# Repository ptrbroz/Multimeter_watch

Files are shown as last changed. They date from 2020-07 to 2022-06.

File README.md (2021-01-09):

# An open-source multimeter watch

Contained herein is the multimeter watch project, developed by Petr Brož and David Šibrava. It is a multimeter small enough to wear on your wrist!  It utilizes the LGT8F328P-QFP32L CPU. 

The developement is ongoing, thus the project's kicad folders are split into different versions for different versions of the hardware:

# V1 prototype

The first version consists of two pcbs, mated via pin headers. The upper pcb holds the I2C display and buttons, as well as the buzzer circuit.  

The bottom pcb holds the CPU, three 3.5mm jack connectors (for custom multimeter probes) and other circuitry.

Sandwiched between the two pcbs is a Li-Po battery, rechargeable via the aforementioned pin headers.

It's features include:

- Timekeeping via I2C RTC
- Voltage, current measuring
- RLC tester functionality
- Programmable current source/sink
- Programmable I2C communication
- Buzzer

For photos of hardware, please scroll to [photos](#Photos).

# V2

The V2 hardware improves upon the V1 in several aspects:

- It changes the signal connection between the top and bottom PCBs from using pin headers to a flex cable. The boards are now held together by screws, allowing for much smaller vertical size. (~halved compared to V1 (todo:add measurements))
- 3.5 jack connectors replaced by S3B-PH-K-S connectors (jacks had poor structural integrity and would come loose with repeated insertions of probes).
- Buzzer circuitry moved to bottom PCB (to allow another slight decrease in vertical dimension).
- Various layout optimizations leading to smaller PCB footprint (42x46mm in V2 as opposed to 46x55mm in V1)

Perhaps most significant is the following improvement:

- Add alternative top PCB which utilizes capacitance-sensing buttons on the PCB itself instead of physical buttons. As the capacitance sensing is driven by an I2C device (an AT42QT1070-S located on the bottom side of the top PCB), 6 pins of the CPU are freed from being used as button inputs.

Thus, when the V2 version is used with the capacitance touch top PCB, up to 6 GPIO pins become available to the user.

# Photos

V1:
(10 CZK coin for scale (diameter = 24.5mm))
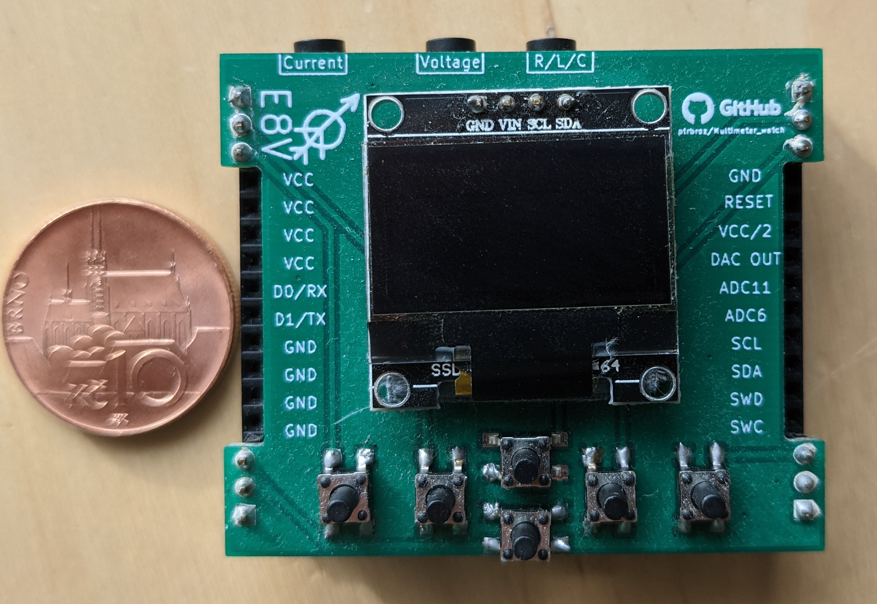
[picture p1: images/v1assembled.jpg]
v1assembled

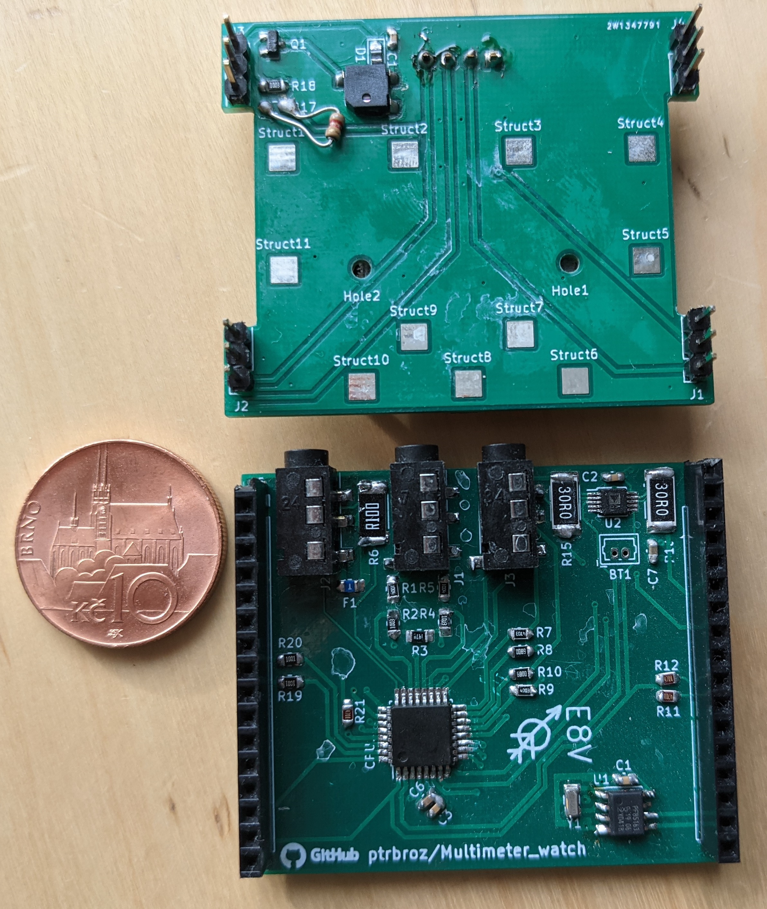
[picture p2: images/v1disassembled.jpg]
v1disassembled

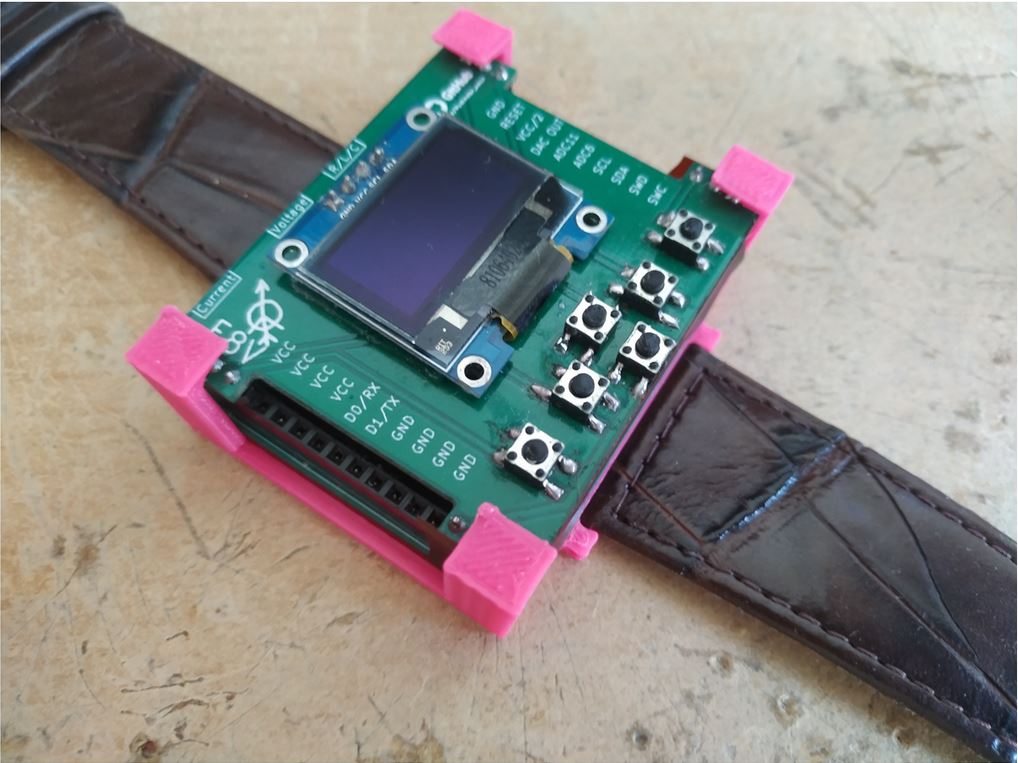
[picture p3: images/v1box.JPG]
v1box


V2:
(to be photographed)

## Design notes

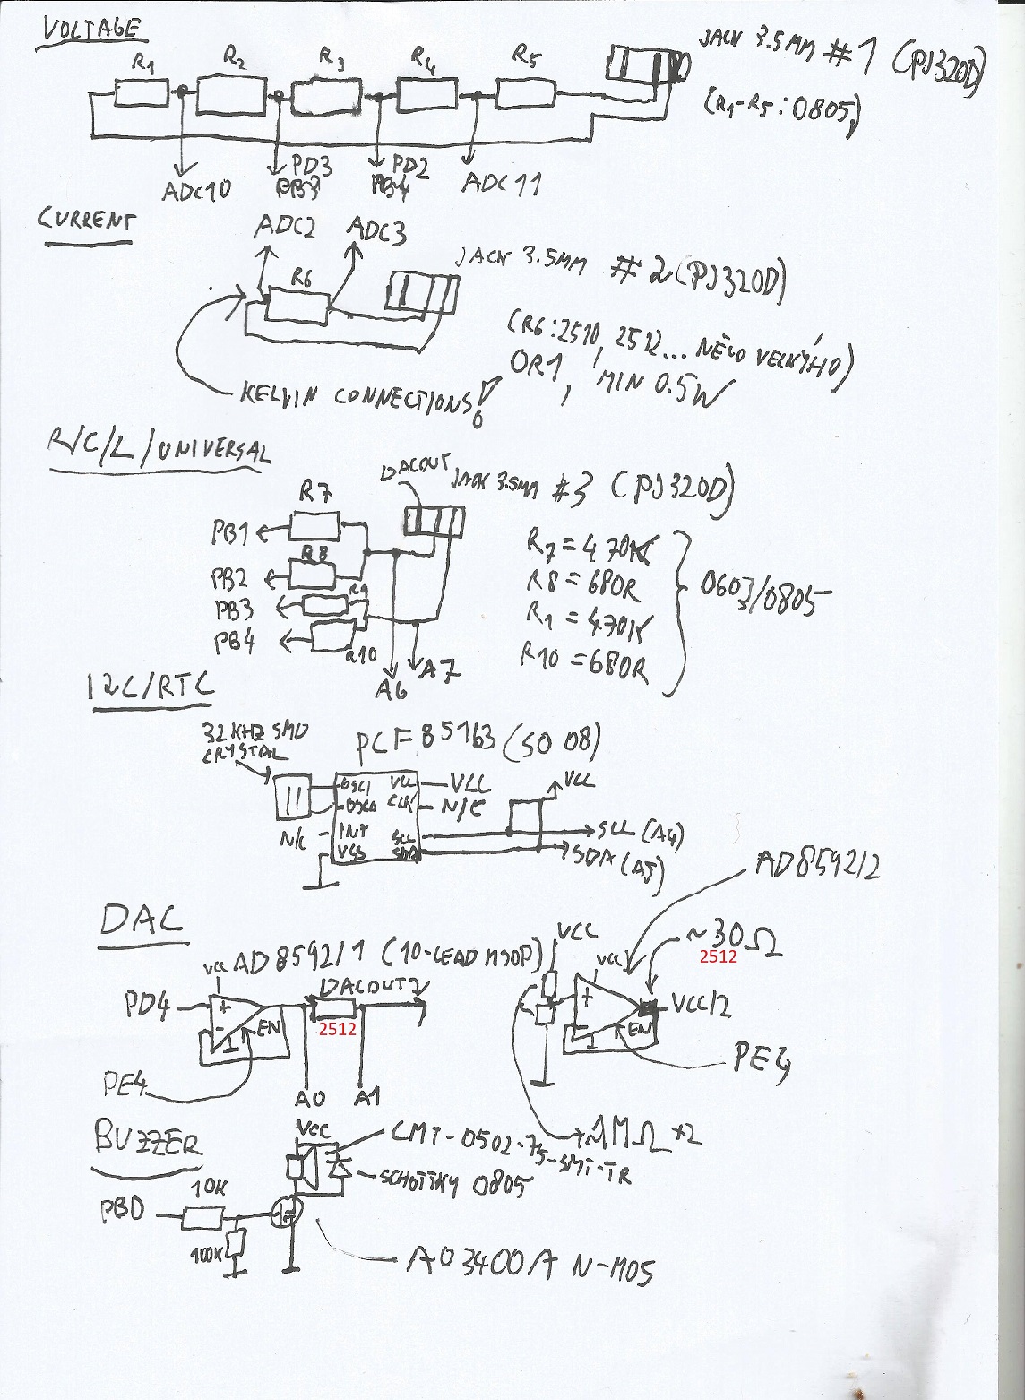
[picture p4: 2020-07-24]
SchemaSketch/page1.jpg

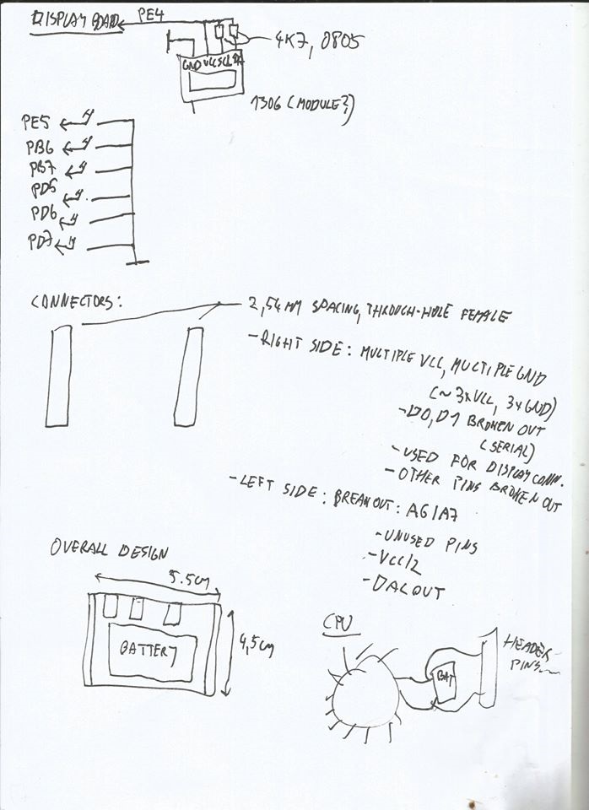
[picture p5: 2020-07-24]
SchemaSketch/page2.jpg

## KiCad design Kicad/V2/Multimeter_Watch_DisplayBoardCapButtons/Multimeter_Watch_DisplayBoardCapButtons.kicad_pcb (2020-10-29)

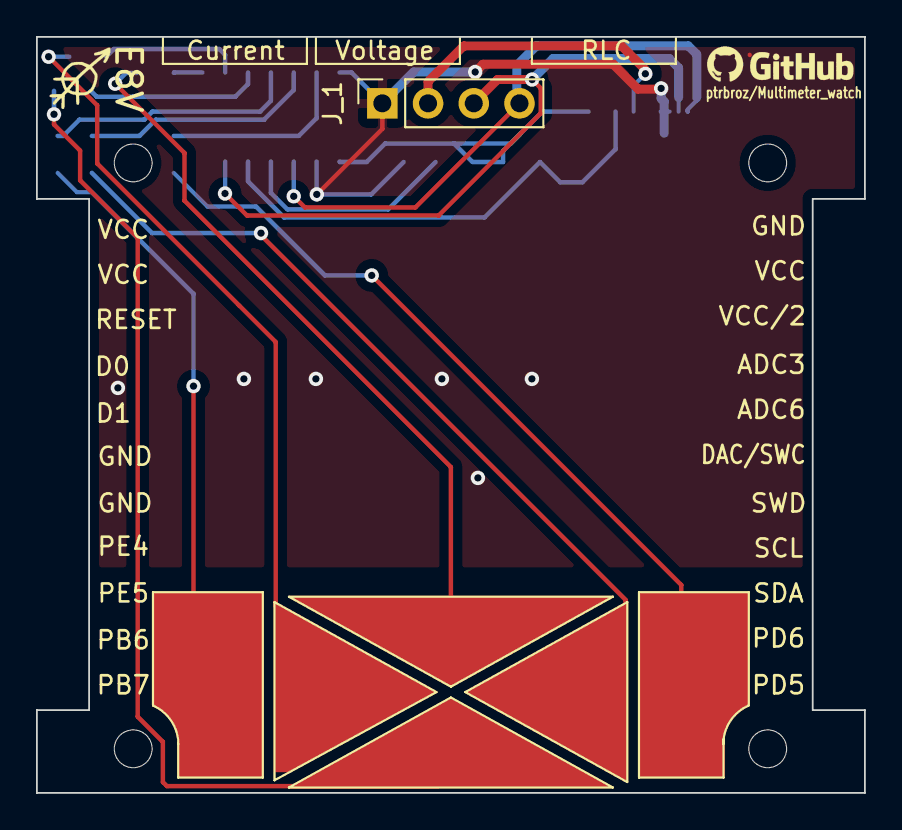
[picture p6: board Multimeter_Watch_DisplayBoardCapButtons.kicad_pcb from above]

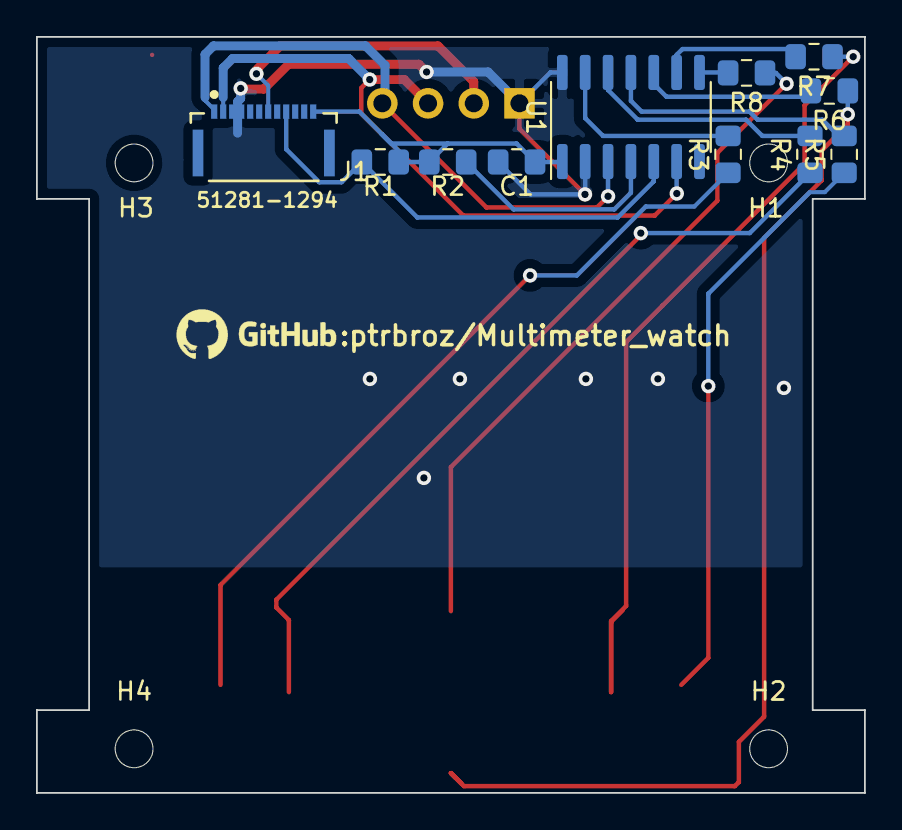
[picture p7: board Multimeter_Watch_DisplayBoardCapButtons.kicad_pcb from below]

Board: 2 copper layers, 46.0 x 42.0 mm, 19 parts (11 on the bottom side), 19 nets.

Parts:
 : Touch_Pad; CapButton_Right
 #2: Touch_Pad; CapButton_Left
C1: C_Small; C_0805_2012Metric_Pad1.15x1.40mm_HandSolder
DIRPAD1: CapButtons_Directional
H1, H2, H3, H4: MountingHole; MountingHole_2.1mm
J1: 51281-1294; Molex-51281-1294-Manufacturer_Recommended
J_1: Conn_01x04_Male; PinSocket_1x04_P2.54mm_Vertical
R1, R2, R3, R4, R5, R6, R7, R8: R; R_0805_2012Metric_Pad1.15x1.40mm_HandSolder
U1: AT42QT1070-S; SOIC-14_3.9x8.7mm_P1.27mm

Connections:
/GND: C1.2, J1.3, J1.4, J_1.1, U1.2, U1.14
/PB5: J1.7, J_1.2
/PB6: J1.9, R1.1, U1.5
/SCL: J1.2, J_1.3, U1.6
/SDA: J1.1, J_1.4, U1.3
/VCC: C1.1, J1.12, R1.2, R2.1, U1.1
unnamed: DIRPAD1.1, R7.1
unnamed: DIRPAD1.2, R4.1
unnamed: DIRPAD1.3, R8.1
unnamed: DIRPAD1.4, R6.1
unnamed: #2.1, R5.1
unnamed: .1, R3.1
unnamed: R2.2, U1.4
unnamed: R3.2, U1.13
unnamed: R4.2, U1.12
unnamed: R5.2, U1.11
unnamed: R6.2, U1.10
unnamed: R7.2, U1.9
unnamed: R8.2, U1.8

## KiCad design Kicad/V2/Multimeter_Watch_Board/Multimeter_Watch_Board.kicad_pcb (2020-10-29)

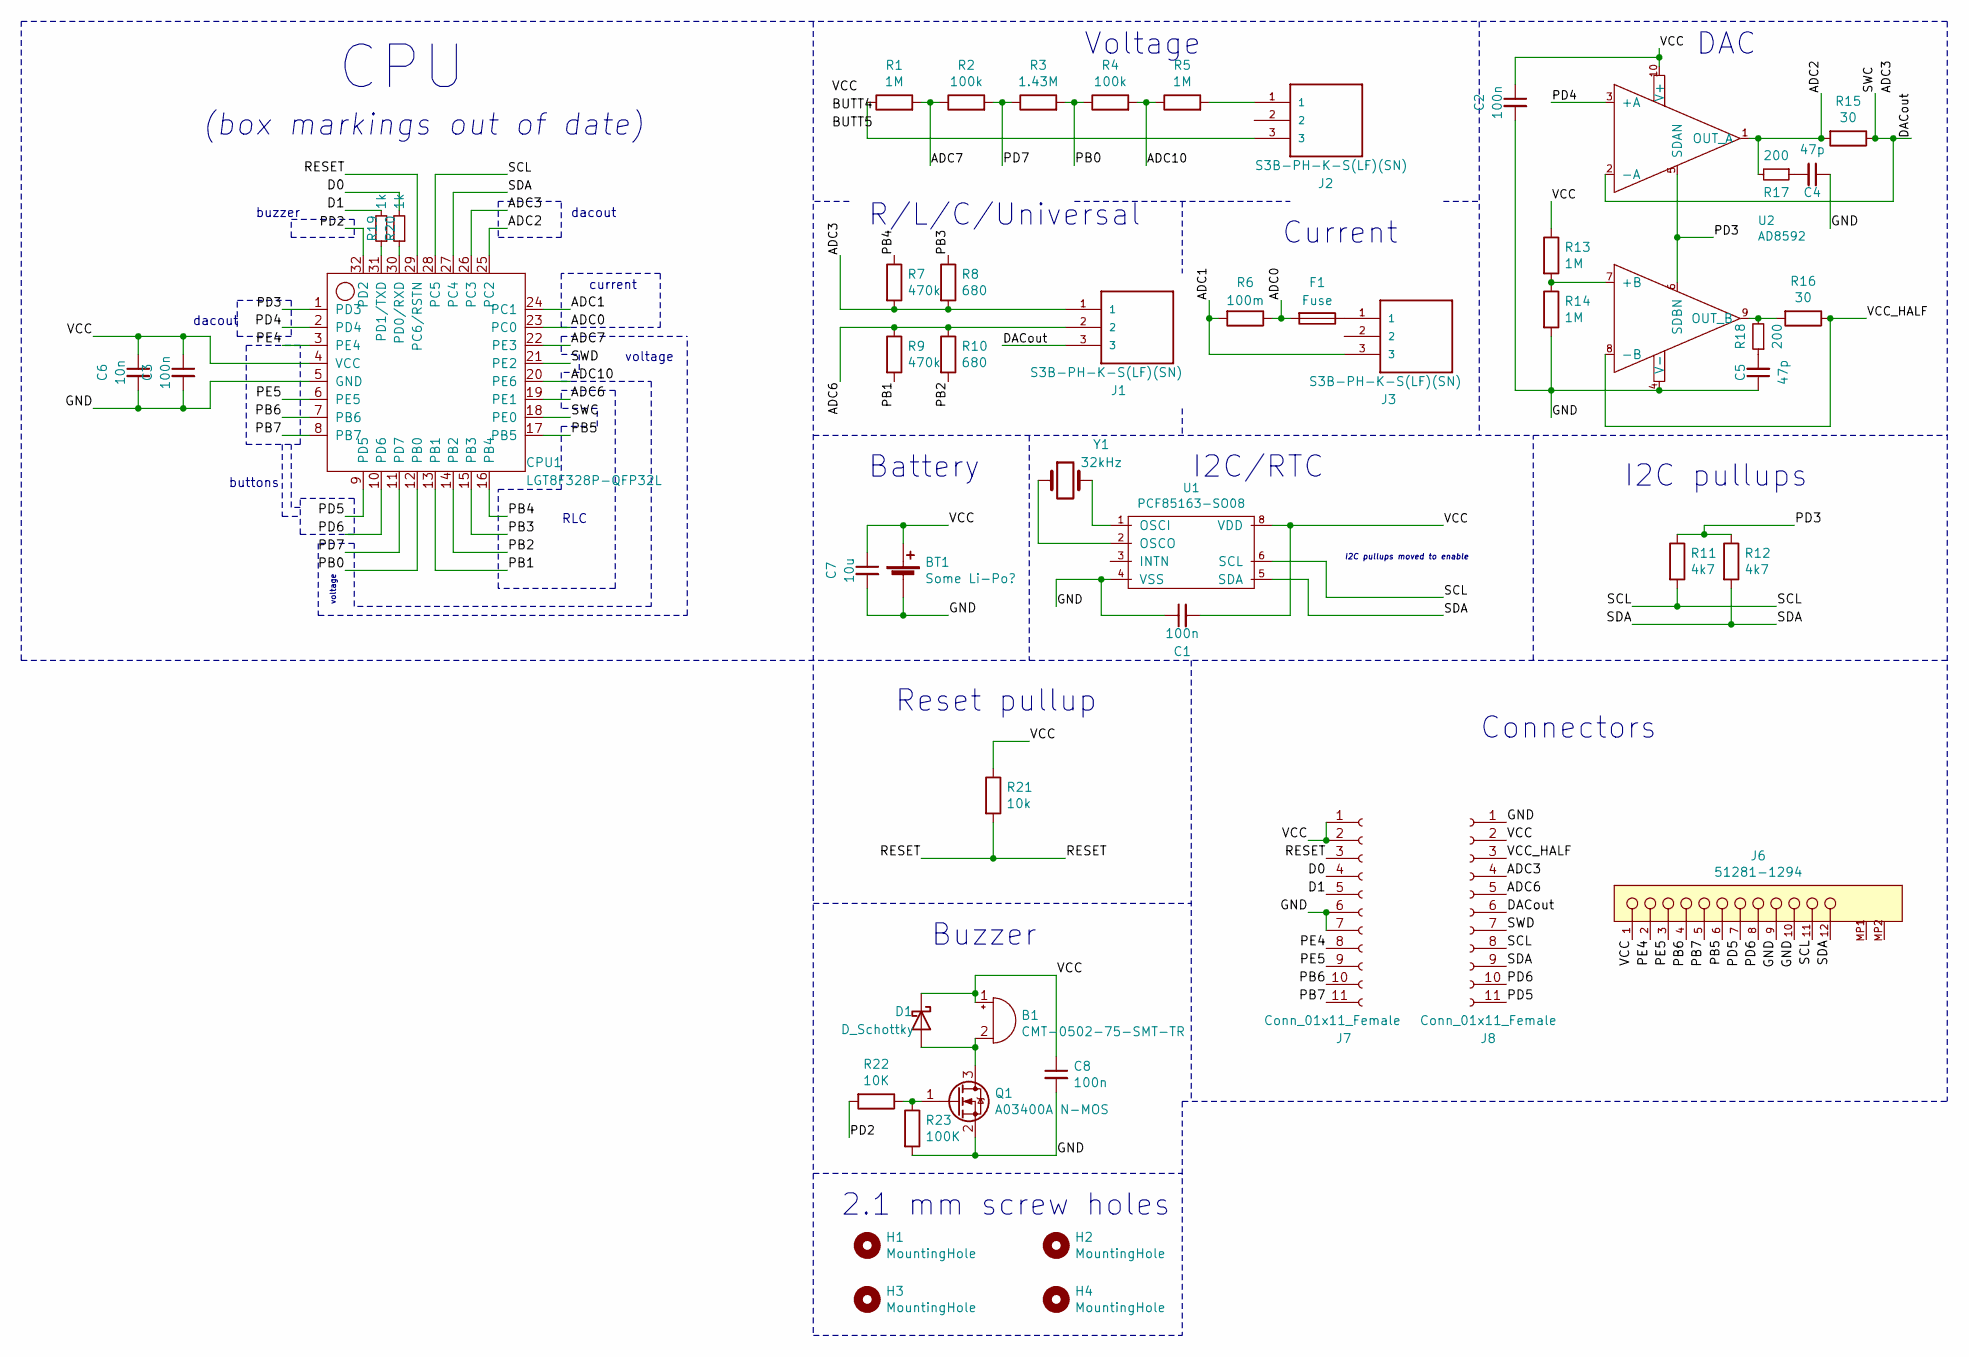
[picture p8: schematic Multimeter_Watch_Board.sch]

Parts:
B1: CMT-0502-75-SMT-TR
BT1: Some Li-Po?; Molex_PicoBlade_53047-0210_1x02_P1.25mm_Vertical
C1, C2, C3, C8: 100n; C_0805_2012Metric_Pad1.15x1.40mm_HandSolder
C4, C5: 47p; C_0805_2012Metric_Pad1.15x1.40mm_HandSolder
C6: 10n; C_0805_2012Metric_Pad1.15x1.40mm_HandSolder
C7: 10u; C_0805_2012Metric_Pad1.15x1.40mm_HandSolder
CPU1: LGT8F328P-QFP32L; TQFP-32_7x7mm_P0.8mm
D1: D_Schottky; D_0805_2012Metric_Pad1.15x1.40mm_HandSolder
F1: Fuse; Fuse_0805_2012Metric_Pad1.15x1.40mm_HandSolder
H1, H2, H3, H4: MountingHole; MountingHole_2.1mm
J1, J2, J3: S3B-PH-K-S(LF)(SN); JST_S3B-PH-K-S(LF)(SN)
J6: 51281-1294; Molex-51281-1294-Manufacturer_Recommended; Voltage Max 50V
J7, J8: Conn_01x11_Female; PinSocket_1x11_P2.54mm_Vertical
Q1: A03400A N-MOS; SOT-23
R1, R5, R13, R14: 1M; R_0805_2012Metric_Pad1.15x1.40mm_HandSolder
R2, R4: 100k; R_0805_2012Metric_Pad1.15x1.40mm_HandSolder
R3: 1.43M; R_0805_2012Metric_Pad1.15x1.40mm_HandSolder
R6: 100m; R_2512_6332Metric_Pad1.52x3.35mm_HandSolder
R7, R9: 470k; R_0805_2012Metric_Pad1.15x1.40mm_HandSolder
R8, R10: 680; R_0805_2012Metric_Pad1.15x1.40mm_HandSolder
R11, R12: 4k7; R_0805_2012Metric_Pad1.15x1.40mm_HandSolder
R15, R16: 30; R_2512_6332Metric_Pad1.52x3.35mm_HandSolder
R17, R18: 200; R_0805_2012Metric_Pad1.15x1.40mm_HandSolder
R19, R20: 1k; R_0805_2012Metric_Pad1.15x1.40mm_HandSolder
R21: 10k; R_0805_2012Metric_Pad1.15x1.40mm_HandSolder
R22: 10K; R_0805_2012Metric_Pad1.15x1.40mm_HandSolder
R23: 100K; R_0805_2012Metric_Pad1.15x1.40mm_HandSolder
U1: PCF85163-SO08; SOIC-8-N7_3.9x4.9mm_P1.27mm
U2: AD8592; MSOP-10_3x3mm_P0.5mm
Y1: 32kHz; Crystal_SMD_3215-2Pin_3.2x1.5mm

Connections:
/ADC0: CPU1.23 (PC0), F1.2, R6.1
/ADC1: CPU1.24 (PC1), J3.3, R6.2
/ADC2: CPU1.25 (PC2), R15.2, R17.2, U2.1 (OUT_A)
/ADC3: CPU1.26 (PC3), J1.1, J8.4, R7.2, R8.2
/ADC6: CPU1.19 (PE1), J1.2, J8.5, R9.1, R10.1
/ADC7: CPU1.22 (PE3), R1.2, R2.1
/ADC10: CPU1.20 (PE6), R4.2, R5.1
/D0: J7.4, R20.2
/D1: J7.5, R19.2
/DACout: CPU1.18 (PE0), J1.3, J8.6, R15.1, U2.2 (-A)
/GND: BT1.2 (-), C1.1, C2.2, C3.2, C4.1, C5.1, C6.2, C7.2, C8.2, CPU1.5 (GND), J6.9, J6.10, J7.6, J7.7, J8.1, Q1.2 (S), R14.2, R23.2, U1.4 (VSS), U2.4 (V-)
/PB0: CPU1.12 (PB0), R3.2, R4.1
/PB1: CPU1.13 (PB1), R9.2
/PB2: CPU1.14 (PB2), R10.2
/PB3: CPU1.15 (PB3), R8.1
/PB4: CPU1.16 (PB4), R7.1
/PB5: CPU1.17 (PB5), J6.6
/PB6: CPU1.7 (PB6), J6.4, J7.10
/PB7: CPU1.8 (PB7), J6.5, J7.11
/PD2: CPU1.32 (PD2), R22.2
/PD3: CPU1.1 (PD3), R11.1, R12.1, U2.5 (SDAN), U2.6 (SDBN)
/PD4: CPU1.2 (PD4), U2.3 (+A)
/PD5: CPU1.9 (PD5), J6.7, J8.11
/PD6: CPU1.10 (PD6), J6.8, J8.10
/PD7: CPU1.11 (PD7), R2.2, R3.1
/PE4: CPU1.3 (PE4), J6.2, J7.8
/PE5: CPU1.6 (PE5), J6.3, J7.9
/RESET: CPU1.29 (PC6/RSTN), J7.3, R21.2
/SCL: CPU1.28 (PC5), J6.11, J8.8, R11.2, U1.6 (SCL)
/SDA: CPU1.27 (PC4), J6.12, J8.9, R12.2, U1.5 (SDA)
/SWD: CPU1.21 (PE2), J8.7
/VCC: B1.1 (-), BT1.1 (+), C1.2, C2.1, C3.1, C6.1, C7.1, C8.1, CPU1.4 (VCC), D1.1 (K), J6.1, J7.1, J7.2, J8.2, R13.1, R21.1, U1.8 (VDD), U2.10 (V+)
/VCC_HALF: J8.3, R16.1, U2.8 (-B)
unnamed: B1.2 (+), D1.2 (A), Q1.3 (D)
unnamed: C4.2, R17.1
unnamed: C5.2, R18.1
unnamed: CPU1.30 (PD0/RXD), R20.1
unnamed: CPU1.31 (PD1/TXD), R19.1
unnamed: F1.1, J3.1
unnamed: J2.1, R5.2
unnamed: J2.3, R1.1
unnamed: Q1.1 (G), R22.1, R23.1
unnamed: R13.2, R14.1, U2.7 (+B)
unnamed: R16.2, R18.2, U2.9 (OUT_B)
unnamed: U1.1 (OSCI), Y1.2
unnamed: U1.2 (OSCO), Y1.1

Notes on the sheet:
Voltage
Current
R/L/C/Universal
I2C/RTC
DAC
Battery
voltage
RLC
current
dacout
dacout
buttons
buzzer
I2C pullups moved to enable
I2C pullups
Reset pullup
Buzzer
Connectors
2.1 mm screw holes
CPU
(box markings out of date)

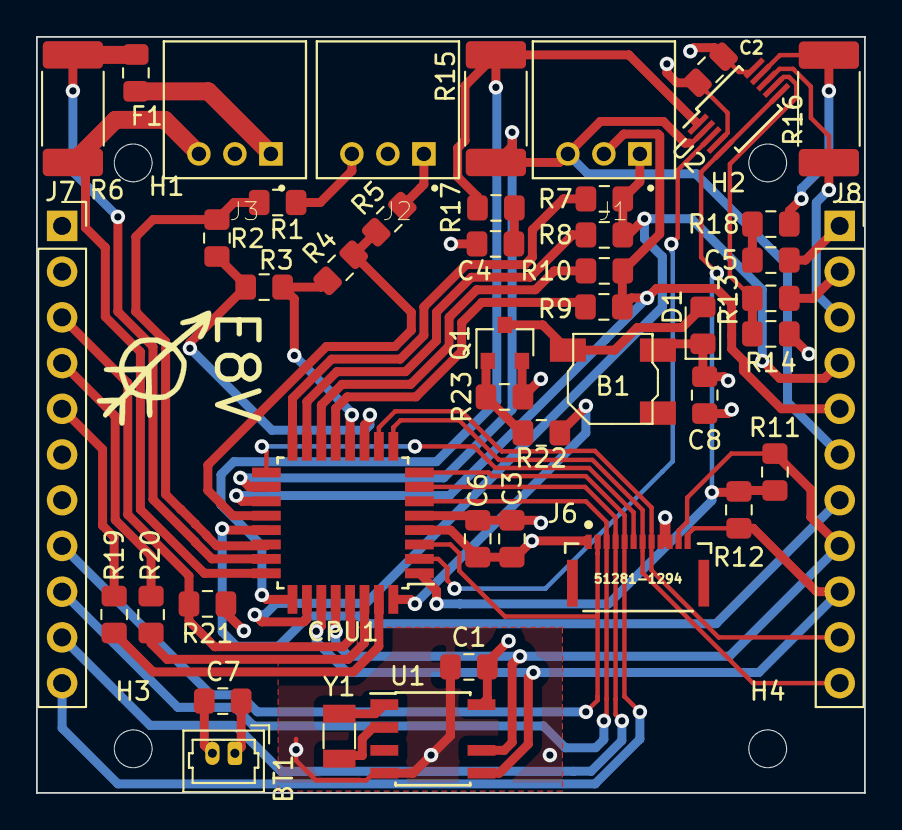
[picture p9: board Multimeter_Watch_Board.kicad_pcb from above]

Board: 4 copper layers, 46.0 x 42.0 mm, 50 parts (0 on the bottom side), 46 nets.

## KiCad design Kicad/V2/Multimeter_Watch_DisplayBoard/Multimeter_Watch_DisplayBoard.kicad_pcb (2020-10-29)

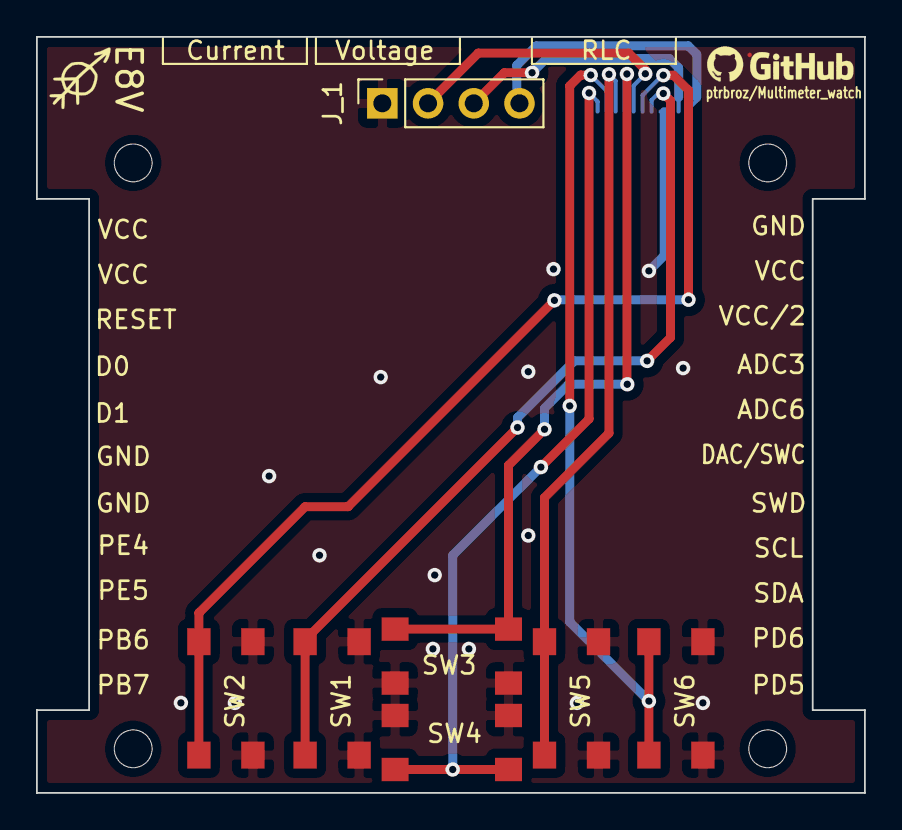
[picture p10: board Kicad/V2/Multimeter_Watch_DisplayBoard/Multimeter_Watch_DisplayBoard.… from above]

Board: 2 copper layers, 46.0 x 42.0 mm, 12 parts (1 on the bottom side), 10 nets.

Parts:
H1, H2, H3, H4: MountingHole; MountingHole_2.1mm
J1: 51281-1294; Molex-51281-1294-Manufacturer_Recommended
J_1: Conn_01x04_Male; PinSocket_1x04_P2.54mm_Vertical
SW1, SW2, SW3, SW4, SW5, SW6: SW_Push; TVCM04N

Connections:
/GND: J1.9, J1.10, J_1.1, SW1.2, SW2.2, SW3.2, SW4.2, SW5.2, SW6.2
/PB5: J1.6, J_1.2
/PB6: J1.4, SW5.1
/PB7: J1.5, SW3.1
/PD5: J1.7, SW2.1
/PD6: J1.8, SW1.1
/PE4: J1.2, SW4.1
/PE5: J1.3, SW6.1
/SCL: J1.11, J_1.3
/SDA: J1.12, J_1.4

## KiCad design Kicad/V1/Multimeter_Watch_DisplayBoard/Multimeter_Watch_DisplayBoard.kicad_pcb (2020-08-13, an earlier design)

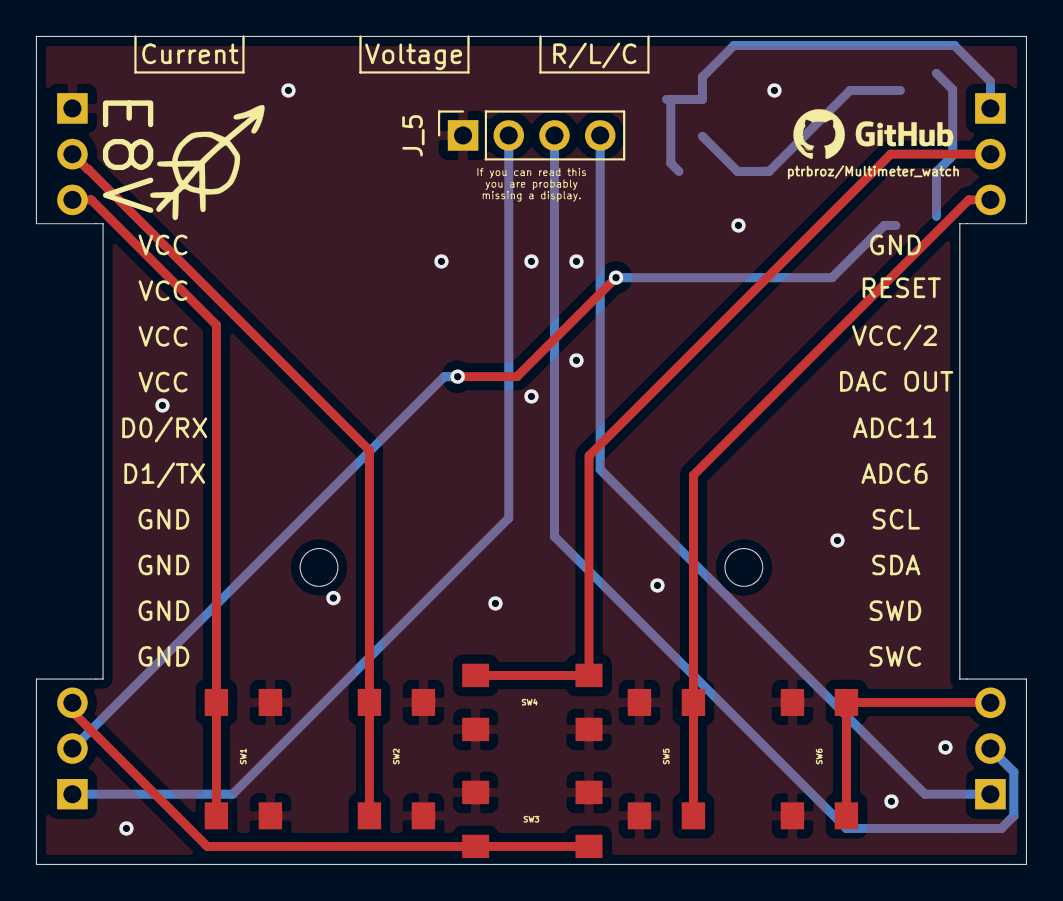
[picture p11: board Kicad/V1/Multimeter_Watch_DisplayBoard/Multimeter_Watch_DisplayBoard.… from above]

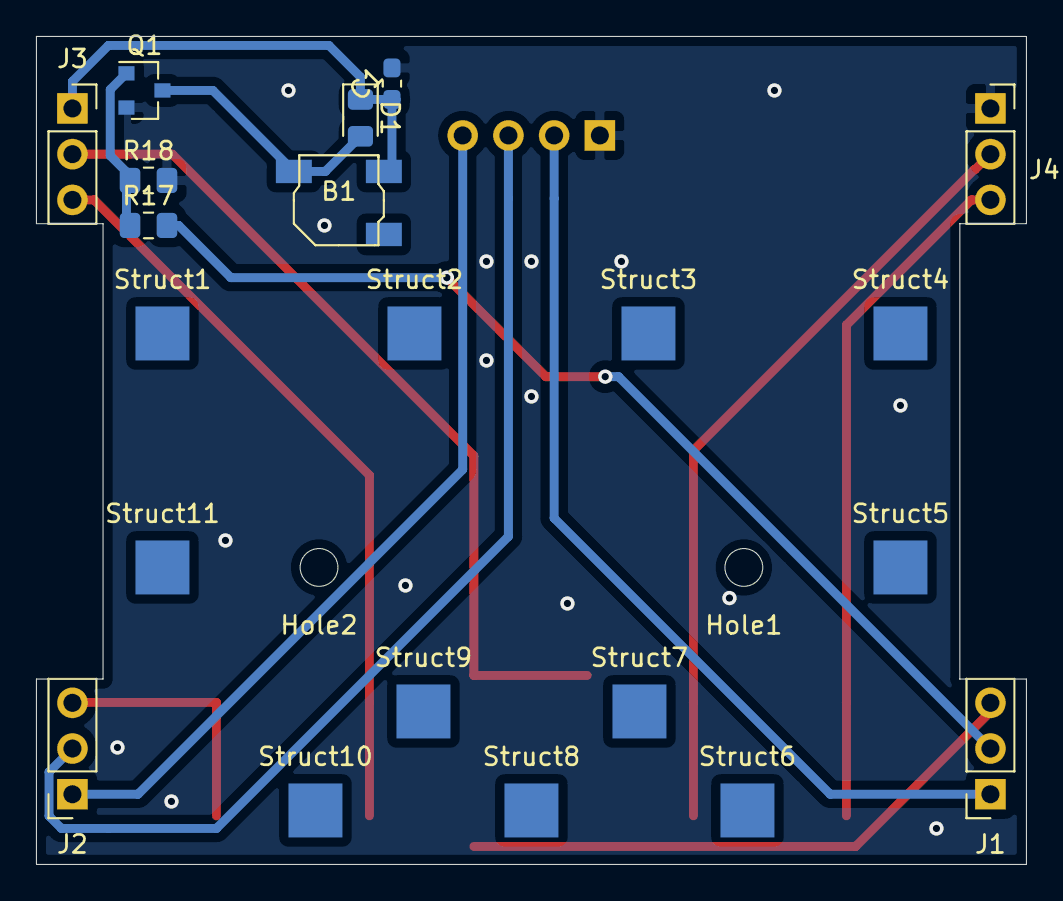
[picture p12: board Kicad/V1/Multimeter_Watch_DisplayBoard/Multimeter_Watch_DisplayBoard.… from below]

Board: 2 copper layers, 55.0 x 46.0 mm, 30 parts (23 on the bottom side), 14 nets.

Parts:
B1: CMT-0502-75-SMT-TR
C1: 100n; C_0603_1608Metric_Pad1.05x0.95mm_HandSolder
D1: D_Schottky; D_0805_2012Metric_Pad1.15x1.40mm_HandSolder
Hole1, Hole2: MountingHole_2.1mm
J1, J2, J3, J4: Conn_01x03_Male; PinSocket_1x03_P2.54mm_Vertical
J_5: Conn_01x04_Male; PinSocket_1x04_P2.54mm_Vertical
Q1: A03400A N-MOS; SOT-23
R17: 10K; R_0805_2012Metric_Pad1.15x1.40mm_HandSolder
R18: 100K; R_0805_2012Metric_Pad1.15x1.40mm_HandSolder
SW1, SW2, SW3, SW4, SW5, SW6: SW_Push; TVCM04N
Struct1, Struct2, Struct3, Struct4, Struct5, Struct6, Struct7, Struct8, Struct9, Struct10, Struct11: StructPad

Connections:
/BUTT1: J4.2, SW2.1
/BUTT2: J4.3, SW1.1
/BUTT3: J1.3, SW3.1
/BUTT4: J3.2, SW4.1
/BUTT5: J3.3, SW5.1
/BUTT6: J2.3, SW6.1
/BUZZER: J1.2, R17.2
/ENABLE: J1.1, J_5.2
/GND: C1.2, J4.1, J_5.1, Q1.2, R18.2, SW1.2, SW2.2, SW3.2, SW4.2, SW5.2, SW6.2
/SCL: J2.2, J_5.3
/SDA: J2.1, J_5.4
/VCC: B1.1, C1.1, D1.1, J3.1
unnamed: B1.2, D1.2, Q1.3
unnamed: Q1.1, R17.1, R18.1

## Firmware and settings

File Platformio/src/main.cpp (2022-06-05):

#include <Arduino.h>
#include "main.h"
#include "wiring_private.h"

#include <SSD1306Ascii.h>

#include <SSD1306AsciiAvrI2c.h>

#include <PinChangeInterrupt.h>

#include "buttons.h"
#include "display.h"
#include "Adafruit5x7_full.h"
#include "snake.h"
#include "program.h"
#include "menu.h"


#include "sleepUtils.h"
#include "measurement.h"
#include "dacUtils.h"
#include "ohmMeter.h"
#include "capacity.h"
#include "waveformGenerator.h"
#include "ncvDetector.h"
#include "resistanceMeter.h"
#include "formula1.h"

int32_t timeTillSleep=10000;
uint8_t *programMemPtr;

void setTimeTillSleep(int32_t _t)
{
timeTillSleep=_t;
}

//------------------------------------------------------------------------------
void setup() {


  pinMode(D3,OUTPUT);
  digitalWrite(D3,HIGH);
  delay(400);
  Serial.begin(115200);
  uint16_t battVoltage=adc_measureBatteryVoltage();
  dac_init();
  //dac_testFunGen();
  dac_output=128;
  Serial.println(battVoltage);
  Serial.println(dac_getVoltageAfterShunt(battVoltage));
  //Serial.println(dac_getVoltageAfterShunt(battVoltage));

//ADMUX = _BV(REFS0) | _BV(MUX3) | _BV(MUX2) | _BV(MUX1);
  //adc_printSettings(battSet);
  // delay(10000);
  initButtons();

  #if RST_PIN >= 0
  oled.begin(&Adafruit128x64, I2C_ADDRESS, RST_PIN);
  #else // RST_PIN >= t
  oled.begin(&Adafruit128x64, I2C_ADDRESS);
  #endif // RST_PIN >= 0
  // Call oled.setI2cClock(frequency) to change from the default frequency.

  oled.setFont(Adafruit5x7);
  tone(2,4000,100);
  return;
  f1_init(NULL);
  while(1)
  {
    f1_loop(NULL);
  }
  return;
  res_loop();
dac_init();

wfg_generate();
//dac_testFunGen();

  while(1)
  {
    dischargeCapacitor();
    uint32_t cap;
    measureCapacity3(false,cap);
  }
  /*while(true)
  {
    Serial.println(ohmmeter_getRawADCLowRange());
  }
  */
}





//------------------------------------------------------------------------------
void loop() {

  funPtr nextFun = NULL;
  programMemPtr = NULL;
;

  oled.clear();


  while(1){
    handleDebouncing();
    handleButtonEdgeDetection();
    handleButtonAutoRepeat();

    if(nextFun == NULL){
      nextFun = getLoopFun();

      if(nextFun == NULL){ //no program running
          nextFun = menu;
      }
    }
    //else: a function is left over from previous loop (probably init or deinit)


    funRetVal ret = nextFun(programMemPtr);

    nextFun = NULL;

    program p = getProgram();

    switch (ret){
    case CONTINUE_LOOP:
        //do nothing
      break;
    case PROGRAM_START:
      setLoopFun(p.loop);
      if(p.requiredRam>0){
        programMemPtr = (uint8_t*)calloc(p.requiredRam, 1);  //might need to handle running out of memory here in the future
      }
      else{
        programMemPtr = NULL;
      }
      nextFun = p.init;
      break;
    case PROGRAM_END:
      setLoopFun(NULL);
      free(programMemPtr);
      programMemPtr = NULL;
      nextFun = p.deinit;
      break;
    }

    
  handleSleeping();
  //delay(1000);
  //sleep_sleepTillWakeup();
  }
}

void handleSleeping()
{
  if(millis()-lastPressMillis>timeTillSleep)
  {
    sleep_sleepTillWakeup();
    lastPressMillis=millis();
    initOled();
  }
}



void initOled()
{
  pinMode(D3,OUTPUT);
  digitalWrite(D3,HIGH);
  delay(50);
  oled.begin(&Adafruit128x64, I2C_ADDRESS);
}

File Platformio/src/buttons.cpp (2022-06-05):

#include "Arduino.h"
#include "buttons.h"

volatile uint8_t buttonsByte = 0;
volatile uint8_t justPressedButtons = 0;
volatile uint8_t justReleasedButtons = 0;
uint8_t autoRepeatPressedButtons=0;
volatile unsigned long lastPressMillis;

  int delayBeforeAutoRepeat=400;
  int autoRepeatRate=250;


void initButtons()
{
    //button pins to inputs
    DDRD &= ~(1 << PD5);
    DDRD &= ~(1 << PD6);
    DDRB &= ~(1 << PB7);
    DDRE &= ~(1 << PE4);
    DDRB &= ~(1 << PB6);
    DDRE &= ~(1 << PE5);
    //enable pullups
    PORTD |= (1 << PD5);
    PORTD |= (1 << PD6);
    PORTB |= (1 << PB7);
    PORTE |= (1 << PE4);
    PORTB |= (1 << PB6);
    PORTE |= (1 << PE5);

    //attach interrupt to the millis timer (timer0); the rest has already been setup by millis
    OCR0A = 0xAF;
    TIMSK0 |= _BV(OCIE0A);
    //attach wakeup interrupt to left button
    PCMSK2|=(1<<PCINT21);//interrupt enable for B2
    PCICR|=(1<<PCIE0);//port B interrupt enable
}

uint8_t getButtonsByteFromPorts(uint8_t _pinB, uint8_t _pinD, uint8_t _pinE)
{
  uint8_t retVal = 0;
  retVal |= ((_pinD >> PD6) & 1) << 0; //button 1
  retVal |= ((_pinD >> PD5) & 1) << 1; //button 2
  retVal |= ((_pinE >> PE4) & 1) << 2; //button 3
  retVal |= ((_pinB >> PB7) & 1) << 3; //button 4
  retVal |= ((_pinB >> PB6) & 1) << 4; //button 5
  retVal |= ((_pinE >> PE5) & 1) << 5; //button 6
  return retVal;
}

void handleButtonEdgeDetection()
{
  justReleasedButtons = 0;
  justPressedButtons=0;
  static uint8_t lastButtonsByte;
  if (buttonsByte != lastButtonsByte)
  {
    justReleasedButtons = ((lastButtonsByte)) & ~buttonsByte;
    justPressedButtons = ~lastButtonsByte & buttonsByte;
    lastButtonsByte = buttonsByte;
    //Serial.println(justReleasedButtons,BIN);
  }
    if(justPressedButtons!=0)
    {
      lastPressMillis=millis();//TODO: maybe handle this in the interrupt for improved accuracy? hmmm
    }
}

void setButtonAutoRepeatRate(int _delayBeforeAutoRepeat, int _autoRepeatRate)
{
  delayBeforeAutoRepeat=_delayBeforeAutoRepeat;
  autoRepeatRate=_autoRepeatRate;
}

void resetButtonAutoRepeatRate()
{
  delayBeforeAutoRepeat=400;
  autoRepeatRate=250;
}

void handleButtonAutoRepeat()
{
  static unsigned long lastMillis=0;
  autoRepeatPressedButtons=0;
  if(millis()-lastPressMillis<delayBeforeAutoRepeat)
  {
    return;
  }
  if(millis()-lastMillis>autoRepeatRate)
  {
    autoRepeatPressedButtons=buttonsByte;
    //Serial.println(autoRepeatPressedButtons,BIN);
    lastMillis=millis();
  }
}

void handleDebouncing()
{
  static unsigned long lastMillis =0;
  static uint8_t pendingRelease;
  static uint8_t buttonsBytePhase0;
  if (millis() - lastMillis < 20)
  {
    return;
  }
  else
  {
    lastMillis = millis();
  }
  static uint8_t phase = 0;
  if (phase == 0)
  {
    pendingRelease = getButtonsByteFromPorts(PINB, PIND, PINE);
    buttonsBytePhase0 = buttonsByte;
    phase = 1;
  }
  else
  {
    uint8_t currentPendingRelease = getButtonsByteFromPorts(PINB, PIND, PINE);
    if (buttonsByte == buttonsBytePhase0 && pendingRelease == (currentPendingRelease))
    {
      //clear the pressed buttons
      buttonsByte &= ~currentPendingRelease;
    }
    phase = 0;
  }
}



SIGNAL(TIMER0_COMPA_vect)
{
  buttonsByte |= ~getButtonsByteFromPorts(PINB, PIND, PINE);
}

EMPTY_INTERRUPT(PCINT0_vect);

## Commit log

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2020-07-23 Rewritten control flow to new version. To be done: solve compiler not seeing program consts
    Program consts defined as they are (eg prog_snake in snake.h) don't work and cause compilation to fail. Supposedly solvable by linking all cpp files when compiling (is that possible in PIO?)
    [main.cpp]
2020-07-23 Fix compilation error (wrong function signatures)
    [main.cpp]
2020-07-24 program memory is now passed as pointer from main instead of being stored in a static pointer within program
    also: fix bug in stopwatch/printSavedMeasures().
    Converted snake and stopwatch programs to new memory handling.
    Todo: convert clockface (?)
    Menu intentionally kept the same (only uses one static byte, which will never be free'd anyway)
    [main.cpp]
2020-07-24 Init kicad project, add sketches
    [Multimeter_Watch_Board_V1.kicad_pcb, Multimeter_Watch_Board_V1.sch]
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2020-07-24 fix shunt resistor
    [Multimeter_Watch_Board_V1.kicad_pcb, Multimeter_Watch_Board_V1.sch]
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2020-07-25 proc. board schematic (mostly) done, fist female connector version
    [Multimeter_Watch_Board_V1.sch]
2020-07-26 start work on pcb layout
    [Multimeter_Watch_Board_V1.kicad_pcb, Multimeter_Watch_Board_V1.sch, Multimeter_Watch_DisplayBoard_V1.kicad_pcb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]
2020-07-26 Switch left and right pin headers (for simpler DACout and VCChalf routing)
    [Multimeter_Watch_Board_V1.kicad_pcb, Multimeter_Watch_Board_V1.sch]
2020-07-26 first attempt at processor board layout
    [Multimeter_Watch_Board_V1.kicad_pcb, Multimeter_Watch_Board_V1.sch]
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2020-07-27 second layout attempt, various pinout changes for better routing
    [Multimeter_Watch_Board_V1.kicad_pcb, Multimeter_Watch_Board_V1.sch]
2020-07-27 Kelvin connections for shunt; minor clearance improvements.
    [Multimeter_Watch_Board_V1.kicad_pcb]
2020-07-28 add measurements, ensure headers are symmetrical
    [Multimeter_Watch_Board_V1.kicad_pcb]
2020-07-28 fix tracks too close after moving header
    [Multimeter_Watch_Board_V1.kicad_pcb]
2020-07-28 measure header distance by center of hole (courtyards are not symmetrical)
    [Multimeter_Watch_Board_V1.kicad_pcb, Multimeter_Watch_DisplayBoard_V1.sch]
2020-07-28 move I2C pullups from VCC to enable
    [Multimeter_Watch_Board_V1.kicad_pcb, Multimeter_Watch_Board_V1.sch]
2020-07-28 display board done, todo: move display down to allow for jack labels
    [Multimeter_Watch_Board_V1.kicad_pcb, Multimeter_Watch_Board_V1.sch, Multimeter_Watch_DisplayBoard_V1.kicad_pcb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]
2020-07-28 Add more decoupling and filtering capacitors; add series resistors for Serial port. Minor improvements.
    [Multimeter_Watch_Board_V1.kicad_pcb]
2020-07-28 display board laid out, added silkscreen desc. of pins and jacks
    [Multimeter_Watch_DisplayBoard_V1.kicad_pcb]
2020-07-28 fix switched I2C pins
    [Multimeter_Watch_Board_V1.kicad_pcb]
2020-07-28 add github, nouth and TGH logos
    [Multimeter_Watch_DisplayBoard_V1.kicad_pcb]
2020-07-28 actually add logos from last commit
    [Multimeter_Watch_Board_V1.kicad_pcb]
2020-07-29 ground plane around crystal, silkscreen adjustments
    [Multimeter_Watch_Board_V1.kicad_pcb, Multimeter_Watch_DisplayBoard_V1.kicad_pcb]
2020-07-29 Add pads on bottom of displayboard
    [Multimeter_Watch_DisplayBoard_V1.kicad_pcb, Multimeter_Watch_DisplayBoard_V1.sch]
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2020-07-29 reset pullup
    [Multimeter_Watch_Board_V1.kicad_pcb, Multimeter_Watch_Board_V1.sch]
2020-07-29 replace temp holes with actual drill holes
    [Multimeter_Watch_DisplayBoard_V1.kicad_pcb]
2020-07-29 group rlc tester pins on right header
    [Multimeter_Watch_Board_V1.kicad_pcb, Multimeter_Watch_Board_V1.sch, Multimeter_Watch_DisplayBoard_V1.kicad_pcb]
2020-07-29 group rlc pins together on right header
    [Multimeter_Watch_Board_V1.kicad_pcb]
2020-07-30 Moved traces from under CPU; start implementing rtc communication and sleeping.
    [Multimeter_Watch_Board_V1.kicad_pcb]
2020-07-30 fix previous commit
    [Multimeter_Watch_Board_V1.kicad_pcb, _saved_Multimeter_Watch_DisplayBoard_V1.sch]
2020-08-13 Refactor button handling and adjust button pinout for compatibility with the new hardware. Implement sleep + wakeup; implement r/w to RTC chip. Fix clock to correctly read the actual value from the R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
    [Multimeter_Watch_Board_V1-B.Cu.gbr, Multimeter_Watch_Board_V1-B.Mask.gbr, Multimeter_Watch_Board_V1-B.Paste.gbr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]
2020-08-13 Re-add the beep (leaving it out causes the system to crash when we run the linear power supply program for some reason)
    [main.cpp]
2020-08-17 Add values for components in schematics; implement voltmeter; fix the bug where the watch goes sleep when the stopwatch is running; try implementing ohmmeter; allow the user to exit power supply app;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
    [Multimeter_Watch_Board_V1.sch]
2020-09-20 Create kicad folder for V2 hw
    [Multimeter_Watch_Board_V1-B.Cu.gbr, Multimeter_Watch_Board_V1-B.Mask.gbr, Multimeter_Watch_Board_V1-B.Paste.gbr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]
2020-09-20 pcb 46x46 area feasibility test (pre dimensions reduction)
    [Multimeter_Watch_Board_V1-B.Cu.gbr, Multimeter_Watch_Board_V1-B.Mask.gbr, Multimeter_Watch_Board_V1-B.Paste.gbr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]
2020-09-20 shrink pcb to 46x42
    [Multimeter_Watch_Board_V2.kicad_pcb]
2020-09-20 wip on measuring circuits
    [Multimeter_Watch_Board_V2.kicad_pcb, Multimeter_Watch_Board_V2.sch]
2020-09-21 wip on V2 board
    [Multimeter_Watch_Board_V2.kicad_pcb, Multimeter_Watch_Board_V2.sch]
2020-09-21 V2 main board layout - first attempt
    [Multimeter_Watch_Board_V2.kicad_pcb, Multimeter_Watch_Board_V2.sch]
2020-09-21 fix thin dacout line
    [Multimeter_Watch_Board_V2.kicad_pcb]
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2020-09-22 silkscreen improvements (bottom board)
    [Multimeter_Watch_Board_V2.kicad_pcb]
2020-09-22 displayboard layout for V2
    [Multimeter_Watch_Board_V2.kicad_pcb, Multimeter_Watch_Board_V2.sch, Multimeter_Watch_DisplayBoard_V2.kicad_pcb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]
2020-09-23 V2 displayboard silkscreen improvements, move display measurements to separate layer
    [Multimeter_Watch_DisplayBoard_V2.kicad_pcb]
2020-09-23 females layout improvements, add silkscreen labels for female pins
    [Multimeter_Watch_Board_V2.kicad_pcb, Multimeter_Watch_Board_V2.sch, Multimeter_Watch_DisplayBoard_V2.kicad_pcb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]
2020-09-24 top board rework (move flex conn up, dedicated display enable)
    [Multimeter_Watch_Board_V2.kicad_pcb, Multimeter_Watch_Board_V2.sch, Multimeter_Watch_DisplayBoard_V2.kicad_pcb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]
2020-09-28 add rlc tester protection to schematic
    [Multimeter_Watch_Board_V2.kicad_pcb, Multimeter_Watch_Board_V2.sch]
2020-09-28 implement rlc protection (likely to be reverted)
    [Multimeter_Watch_Board_V2.kicad_pcb, Multimeter_Watch_Board_V2.sch]
2020-09-29 Revert "implement rlc protection (likely to be reverted)"
    This reverts commit 3bbffdcc62f9ba327af4a0488dca8880d003efb7.
    [Multimeter_Watch_Board_V2.kicad_pcb, Multimeter_Watch_Board_V2.sch]
2020-09-29 Revert "add rlc tester protection to schematic"
    This reverts commit df46bc8d5560e11f4e55d6f466ca62c966db9fe4.
    [Multimeter_Watch_Board_V2.kicad_pcb, Multimeter_Watch_Board_V2.sch]
2020-09-29 make V2 displayboard use same pinout for buttons as V1
    [Multimeter_Watch_DisplayBoard_V2.kicad_pcb, Multimeter_Watch_DisplayBoard_V2.sch]
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2020-09-30 change kicad project naming (versions now distincted by folder)
    [Multimeter_Watch_Board.kicad_pcb, Multimeter_Watch_Board.sch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]
2020-09-30 wip capacitive board - first concept of buttons shape
    [Multimeter_Watch_DisplayBoardCapButtons.kicad_pcb, Multimeter_Watch_DisplayBoardCapButtons.sch]
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2020-10-08 move battery connector, fix silkscreen labeling of females
    [Multimeter_Watch_Board.kicad_pcb, Multimeter_Watch_DisplayBoard.kicad_pcb]
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2020-10-11 change voltage/current connector setup from pins 1-2 to 1-3 for greater distance between voltage input pins
    [Multimeter_Watch_Board.kicad_pcb, Multimeter_Watch_Board.sch]
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2020-10-18 Keepout and silkscreen changes to capacitance top board
    [Multimeter_Watch_DisplayBoardCapButtons.kicad_pcb]
2020-10-18 fix flex conn
    [Multimeter_Watch_DisplayBoardCapButtons.kicad_pcb, Multimeter_Watch_DisplayBoardCapButtons.sch]
2020-10-29 drc update and fixes to capbuttons board
    [Multimeter_Watch_DisplayBoardCapButtons.kicad_pcb, Multimeter_Watch_DisplayBoardCapButtons.sch]
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2020-10-29 drc update and fixes to bottom board
    [Multimeter_Watch_Board.kicad_pcb]
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2021-12-28 Start developing the waveform generator and the capacitance measurement features.
    [_saved_Multimeter_Watch_DisplayBoardCapButtons.sch]
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
